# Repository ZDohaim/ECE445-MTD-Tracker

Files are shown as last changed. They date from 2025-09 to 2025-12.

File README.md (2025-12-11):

# ECE445-MTD-Tracker

## Champaign MTD Bus Tracker Map
Team Members:
Amber Wilt (anwilt2)
Daniel Vlassov (dvlas2)
Ziad Aldohaim (ziada2)
Problem
Champaign has a very large and complex bus system through the MTD. It can be hard for students to know when the buses are coming when they are in buildings such as the ECEB, since the bus times are only displayed at the stops. Furthermore, these buses can be late or early, causing students to miss their bus or not arrive at their destination on time.

### Solution
To fix this, we will come up with the design for a large display that shows real-time locations of all buses (color-coded using RGB) in the surrounding campus area. This can be used by students in buildings to easily visualize where the bus they want to take is currently located, making it easier for students to time when to leave classrooms and when to expect their ride. The display will update the locations approximately every 30 seconds and will light up every LED along a bus route every few minutes to make it easier for students to visualize which bus route they need to take. Furthermore, the system will include various light settings (theme/brightness).

### Solution Components
This system will mainly include the subsystems of the LED matrix, the controller, and the power supply.

#### Subsystem 1 - LED Matrix
The LED matrix will be located on a large PCB or 3D printed map of the city (cost dependent). This subsystem will be made of addressable LEDs, photoresistors to automatically modify the intensity of LEDs, and will be controlled by the microcontroller (to indicate positions).

#### Subsystem 2 - Microcontroller
The microcontroller will utilize wifi to access the MTD API to gather real-time bus data as well as provide control to individually address each LED within the matrix. Furthermore, it will control/communicate with other modules/displays in the system, such as a real-time clock or menu. The microcontroller will be an ESP32

#### Subsystem 3 - Power Supply
The power supply will provide ample power to a large number of LEDs (and the entire system). We will need to include a buck converter to step down the power supply to be usable by the LEDs.

## Criterion for Success
To demonstrate the success of our project, we will need to prove the accuracy of the data we are displaying (how accurate are bus timings/locations). Additionally, we will need to show that the data is easy to interpret for a user and can be utilized for easier bus system use.

## Demo Video
https://youtube.com/shorts/ADJun_s7ysQ?si=JwPbscHMFlE2qaHY

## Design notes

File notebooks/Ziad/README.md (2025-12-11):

# Ziad's Notebooks

## Week 1-2: September 29-October 5, 2025
### API Setup and Initial Testing

**Date: 09/24/2024**

**Objective:** Get MTD API and validate data structure

**Tasks Completed:**
- Registered and Received API key, from MTD and completed verification process.
- Set up Insomnia REST client for API testing
- Tested endpoints
 
Screenshot 2025-09-28 at 3 54 33 PM

- Retrieved JSON responses from all endpoints

**API Response Structure:**
```json
{
  "vehicles": [
    {
      "vehicle_id": "...",
      "trip": {
        "route_id": "ILLINI",
        "direction": "East"
      },
      "location": {
        "lat": 40.1092,
        "lon": -88.2272
      }
    }
  ]
}
```

## Week 3-4: October 6-12, 2025
### ESP32 Integration and Breadboard Demo

**Date: 10/05/2024**
**Some Issues faced: 

1. **TLS Certificate Validation:** Initially failed HTTPS connection
 Used `client.setInsecure()` to bypass certificate validation (acceptable for read-only public API)
2. **Using IllinoisNet**
  - Failed to connect to IllinoisNet due to Captive Portal to log in to student account, opted to using phone hotspot.

B54E72DD-15F0-4063-979C-1600B46E0ABB_1_105_c

**Flowchart**

Screenshot 2025-12-11 at 2 07 16 PM

## Week 5-6: October 13-27, 2025
### GPS Mapping Algorithm and LED Integration
**Date: 10/13/2024**
**Objective:** Test basic LED control and display live bus data for Illini Union Bus Stop Mock Demo 2

- Connected to MTD API and fetched live vehicle data
- Filtered JSON response for Illini Union route buses only
- Extracted latitude and longitude for each bus
- Applied simple linear scaling to approximate LED positions, based on (176 LEDs) small LED strip we have
- Updated LEDs every 60 seconds with new API data
**JSON Parsing Code:**
```cpp
for (JsonObject vehicle : doc["vehicles"].as()) {
    const char* route_id = vehicle["trip"]["route_id"];
    
    // Filter for Illini Union only
    if (strcmp(route_id, "ILLINI") == 0) {
        double lat = vehicle["location"]["lat"];
        double lon = vehicle["location"]["lon"];
        
        // Basic position estimation (simplified)
        int led_position = estimatePosition(lat, lon);
        strip.setPixelColor(led_position, strip.Color(255, 255, 255)); 
    }
}
strip.show();
```

https://github.com/user-attachments/assets/0354b601-5e5d-42b3-8681-6bb49f9fb9fd

## Week 7-9: October 27 - November 2, 2025
**Task:** Get Machine Shop Stand

### Machine Shop Coordination

- Get Board so Daniel can glue 3D printed segments of the map on it. 

Items from Machine Shop:

651D2E2C-DB3E-4684-9555-0176D12105F5_4_5005_c

## Week 10: November 3-9, 2025
**Task:** Finalize Code

### GPS Mapping Algorithm Development

**Objective:** Develop accurate GPS-to-LED coordinate transformation algorithm

**Problem Statement:**
Convert GPS coordinates (latitude/longitude) to discrete LED indices (0-873) representing exact physical positions on the map.

### Two-Step Algorithm

**Segment Identification**
- Defined 16 street segments with GPS bounding boxes
- Each segment has `minLat, maxLat, minLon, maxLat` boundaries

**Data Structure:**
```cpp
struct GPStoLED {
    const char* segment_name;
    std::vector ranges;
    double minLon, maxLon;
    double minLat, maxLat;
    bool reverse;
};
```
## Week 10: November 10-23, 2025
**Task** Finalize Code

### GPS Mapping, 

Segmented the Longitude and Latitude incorrectly, Amber and Daniel fixed.
Added functionality of the buttons, got stuck on the legend and holding button functionality, Daniel finalized it.
**Flowchart for button functionality**

Screenshot 2025-12-11 at 2 07 57 PM

Added photoresistor and brightness functionallity. 
Had to adjust some Routes, since the LEDs are connected serially and where a bit random based on the direction and the actual LED segment, so Amber helped a lot with diving that up and testing.

## Week 11: December 1-11, 2024
**Demo and Final Presentation Done** 

BUS DEMO

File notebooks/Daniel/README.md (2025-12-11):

# Daniel's Notebooks

This directory contains Daniel's notebooks and work for the ECE445 MTD Tracker project.

- 2025-09-03 - RFA Creation
- 2025-09-10 - Proposal Creation
- 2025-09-14
# 2025-09-3 - Brainstorming & RFA
First meeting to come up with potential ideas for senior design project.
- Initial Ideas:
  - 3D Printed Battle Bots - join the battle bot competition with professor gruev
  - Pill Sorter - automatically sort pills by days needed
  - Automatic Frozen Fish Feeder - keeps fish food frozen and automatically feeds the fish
  -nd  MTD Bus Visual - Live feed of the buses on campus ashows them on PCB/3D printer*

- MTD Bus Tracker Project Idea:
  - live tracking every 30 sec
  - two-way LED roads along 3d printed champaign
  - maybe include brightness, themes
  - 7-segment display for time or date?
  
# 2025-09-10 - Proposal Creation
Meeting to start creating proposal documentation
- Daniel: Visual aid and a block diagram.
- Brainstormed what the block diagram needs and what components we should consider using.

# 2025-09-14 - Block Diagram and Visual Aid
- Visual Aid
Visual Aid
  
- Block Diagram
blockDiagram

# 2025-09-20
- Basic design of the 3d model, making it simpler and figuring out the size

# 2025-10-6 
- Lab meeting, built out a simple breadboard with the LEDs, LED chase, button control, and photoresistor analog input.
- Added the Arduino code

# 2025-10-7
-Started the first 3d prints to get options for scale 
-3dmap

# 2025-10-14
-Design Doc Done
  
# 2025-10-14 - 11-20
-3d printing 25 tiles for the map

# 20205-10-20 - PCB Layout Rev1
- Routed all the traces on a PCB for the first iteration passes all PCB way tests
pcbrev1

# 2025-10-27 - TA Meeting: Breadboard Demo 2
-We showed tracking buses on a mock 3d map with a functioning PCB

# 2025-11-2 - PCB Soldering
-Soldered PCB
-tested all of the traces to make sure they work
-The linear regulator kept burning out
-Using bench power, able to flash simple test code to light up RGB LED

# 2025-11-10 - PCB Layout Rev 2
-Routed all the traces on the new iteration of the board, changed most of the layout to feature better placement of components, and new power system
pcbrev2

# 2025-11-11 - TA Meeting
-Still 3D printing the model 

# 2025-11-13 - Soldering PCB
- Soldered the new PCB rev 2 board and did the same test to make sure power and ESP32 flashing works, not tested on wall power
- PCBrev3

# 2025-11-18 - TA Meeting
-Demonstrated new PCB functioning on bench power supply and additional mapping of buses on LED strip

# 2025-11-29 - Physical Assembly Done
-Physically glued all 25 plates to the backboard and started designing a custom 3d printed border 
assebmled

# 2025-12-30 - Routing Led Strips
-Spent most of the day routing led strips through all roads buses go
-Worked on code for color matching to buses

# 2025-12-10 - Final Demo
-Final project with a custom menu for bus route selection
demo

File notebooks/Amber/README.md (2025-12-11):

# Amber's Notebooks
This directory contains Amber's notebooks and work for the ECE445 MTD Tracker project.

- 2025-09-03 - RFA Creation
- 2025-09-10 - Proposal Creation
- 2025-09-28 - Initial PCB Design
- 2025-10-2 - PCB Design and Components
- 2025-10-6 - More PCB Design and Components

# 2025-09-3 - Brainstorming & RFA
First meeting to come up with potential ideas for senior design project.
- Initial Ideas:
  - 3D Printed Battle Bots - join the battle bot competition with professor gruev
  - Pill Sorter - automatically sort pills by days needed
  - Automatic Frozen Fish Feeder - keeps fish food frozen and automatically feeds the fish
  - MTD Bus Visual - Live feed of the buses on campus and shows them on PCB/3D printer*

- MTD Bus Tracker Project Idea:
  - live tracking every 30 sec
  - two-way LED roads along 3d printed champaign
  - maybe include brightness, themes
  - 7-segment display?
  
# 2025-09-10 - Proposal Creation
Meeting to start creating proposal documentation
- Amber: make the introduction (problem and solution)
- Problem: students find bus routes too confusing, miss bus
- Solution: high-level design, why this is better than just a screen

# 2025-09-29 - PCB Design

- use the ESP32 s3 wroom 1 (wifi)

# 2025-10-2 - PCB Design and Components
- CL21A226MAQNNNE - 22uF
- CC0805KRX7R9BB104 - 100nF (2)
- CL21B105KBFNNNE - 1uF

- 

- Working File Uploaded

# 2025-10-6 - More PCB Components
-Capacitors:
  - [CL21A226MAQNNNE](https://www.digikey.com/en/products/detail/samsung-electro-mechanics/CL21A226MAYNNNE/10479857) - 22uF (decouple capacitor)
  - [CC0805KRX7R9BB104](https://www.digikey.com/en/products/detail/yageo/CC0805KRX7R9BB104/302874) - 0.1uF (4)   (decouple capacitor, enable capacitor, photoresistor capacitor)
  - [CL21B105KBFNNNE](https://www.digikey.com/en/products/detail/samsung-electro-mechanics/CL21B105KBFNNNE/3886687) - 1uF    (boot capacitor)
  - [TAJA106K016RNJ](https://www.digikey.com/en/products/detail/kyocera-avx/TAJA106K016RNJ/563762) - 10uF   (step down polarized capacitor)
  - [TCJB226M025R0150E](https://www.digikey.com/en/products/detail/kyocera-avx/TCJB226M025R0150E/10062672)](https://www.digikey.com/en/products/detail/kemet/T529P226M010AAE200/4246277) - 22uF   (step down   polarized capacitor)
  - barrel jack - https://www.digikey.com/en/products/detail/same-sky-formerly-cui-devices/PJ-080BH/3477153
  - USB - https://www.mouser.com/ProductDetail/GCT/USB4216-03-A?qs=Tc%252BHE9vUsnv1G2UWLFIexA%3D%3D
  - fuse - https://www.digikey.com/en/products/detail/bel-fuse-inc/0ZCF0500FF2A/10445775
  - Cap - https://www.digikey.com/en/products/detail/vishay-sfernice/T73YP103KT20/1587813
  - 3pin led connector - https://www.digikey.com/en/products/detail/te-connectivity-amp-connectors/282837-3/2187974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

# 2025-10-7: TA Meeting
- First PCB iteration due, reviewed design and submission
- Breadboard demo 1 - showed lighting up LED with breadboard

# 2025-10-14: TA Meeting
- Design document done

# 2025-10-16 - More PCB Design Work
- ESP32-S3 set up: (reference: https://documentation.espressif.com/esp32-s3-wroom-1_wroom-1u_datasheet_en.pdf)
  - 
  - 
  - https://www.youtube.com/watch?v=EdEwRXiQsfc  (microcontroller schematic design example)
  - https://www.youtube.com/watch?v=xK14eVJCoqU   (microcontroller schematic design example)
  - 

  - set up microcontroller based on datasheet and video references, as well as usb, boot/enable buttons, and input
 
# 2025-10-18 - Power Distribution Design
- Choose to use linear regulator for 5V to 3.3V step-down voltage from barrel jack input using
- Datasheet: http://www.advanced-monolithic.com/pdf/ds1117.pdf
- Preliminary Design:
  - 
- Logic level shifter for 3.3V to 5V step-up for LED data line:
  - Based off of schematic for SparkFun logic-level bidirectional
  - Data sheet: https://cdn.sparkfun.com/datasheets/BreakoutBoards/Logic_Level_Bidirectional.pdf
  - Example Schematic: 
  - Implemented Design: 

# 2025-10-20 - Photosensor Circuit
- Use analog output for ambient lights could use digital for 0 or 1 value
- 

# 2025-10-27 - TA Meeting: Breadboard Demo 2
- Showed actual tracking of buses along green street

# 2025-11-3 - PCB Testing
- soldered PCB and tested
- able to flash microcontroller via USB after trial/error and could light up debugging LEDs with code
- linear regulators don't work with wall supply
- have to redesign power distribution system and microcontroller set up

# 2025-11-10 - Second PCB Design
- New microcontroller set up for EN and Boot correct oritentation:
  -
- New power distribution circuit using a 5V to 3.3V converter to handle input noise or spikes in current/voltage draw
  - 

# 2025-11-11 - TA Meeting
- no new design changes, working on 3D printing (Daniel) and assembly

# 2025-11-18 - TA Meeting (Mock Demo)
- showed working PCB with programmable microcontroller and additional programming for mapping buses to the actual LED strips

# 2025-11-30 - Physical Assembly Done
-

# 2025-12-1 - Finishing Code
- created the coordinate mappings for each street mapped onto the display via google maps and used counter code to find the LED ranges for each strip
- example of mapping:  
- adjusted code for the mapping of LEDs now onto a one-way road

# 2025-12-10 - Final Demo :))))
- final design:
  -

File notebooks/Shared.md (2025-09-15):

# Shared Notebook:

# 03-09-2025 Brainstorming & Created RFA 
First time meeting as a team. We brainstormed different ideas:

Pill Sorter - automatically compartmentalize pills by days needed, just dump into dispenser and it does everything.
3D Printed Battle Bots - join the battle bot competition with professor Gruev
Automatic Frozen Fish Feeder - keeps fish food frozen and automatically feeds the fish
#MTD Bus Visual - Live feed of the buses on campus and shows them on PCB/3D printer

# 10-09-2025 Drafting with Proposal

Finalized the idea, and what was needed, split up the Proposal:
1. Introduction (Amber)
2. Design (Daniel)
3. Ethical Considerations (Ziad)

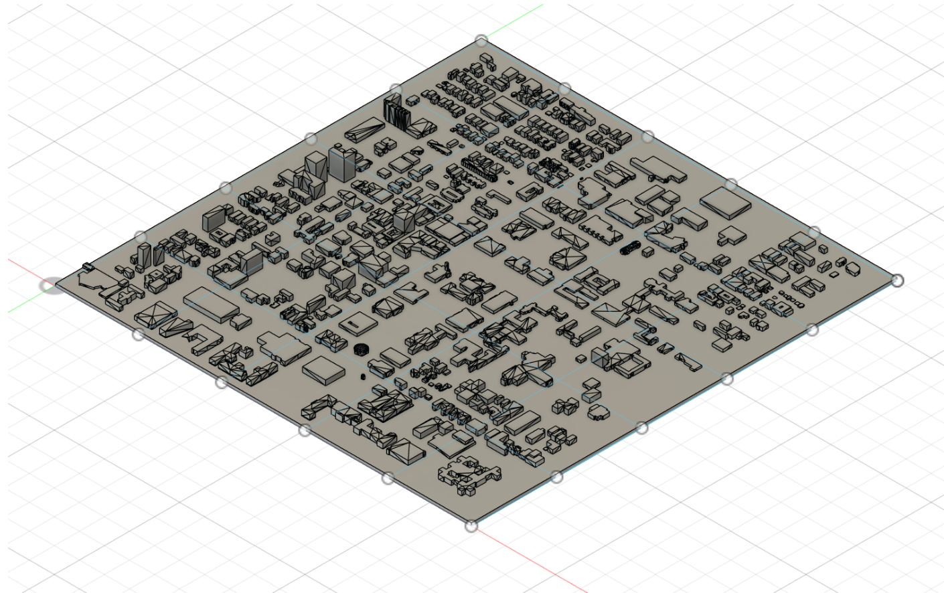
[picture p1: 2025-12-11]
notebooks/Daniel/3dmap.PNG

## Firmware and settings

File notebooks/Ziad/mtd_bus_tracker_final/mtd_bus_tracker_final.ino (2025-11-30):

#include <Wire.h>
#include <Adafruit_SSD1306.h>
#include <Adafruit_GFX.h>
#include <Adafruit_NeoPixel.h>
#include <ArduinoJson.h>
#include <WiFi.h>
#include <HTTPClient.h>
#include <WiFiClientSecure.h>

// WiFi credentials
const char* ssid = "iPhone";
const char* password = "11111111";

// MTD API endpoint
const char* apiURL = "https://developer.mtd.org/api/v2.2/json/GetVehicles?key=13d4773418a343cc902e31242d674e67";

// Pin definitions
#define PHOTORESISTOR_Analog 47
#define PHOTORESISTOR_out 39
#define BUTTON1_PIN 9
#define BUTTON2_PIN 10
#define BUTTON3_PIN 11
#define LED_PIN 3
#define LED_REDPIN 17
#define LED_GREENPIN 18
#define LED_BLUEPIN 8
#define NEOPIXEL_PIN 16
#define OLED_SDA_PIN 39
#define OLED_SCL_PIN 38
#define SSD1306_I2C_ADDRESS 0x3C

// LED strip setup
#define NUM_LEDS 1100
Adafruit_NeoPixel strip(NUM_LEDS, NEOPIXEL_PIN, NEO_GRB + NEO_KHZ800);

// OLED setup
#define SCREEN_WIDTH 128
#define SCREEN_HEIGHT 64
Adafruit_SSD1306 display(SCREEN_WIDTH, SCREEN_HEIGHT, &Wire, -1);

// Timing constants
#define API_UPDATE_INTERVAL 60000   // 60 seconds
#define ANIMATION_STEP_MS 25        // 25ms per LED (animation)


struct GPStoLED {
  const char* segment_name;
  float lat_min, lat_max; 
  float lon_min, lon_max;
  const char* orientation;  
  int led_out_start;        // going south [outbound (South/East/Urbana)]  [CHANGE THESE VALUES]
  int led_out_end;
  int led_in_start;         //going north [inbound (North/West/Champaign)] [CHANGE THESE VALUES]
  int led_in_end;
};



GPStoLED gps_mappings[] = {
  // WHITE STREET (East-West)
  {"White Third-Fourth", 40.114337, 40.114537, -88.235518, -88.233441, "EW", 0, 20, 20, 40},
  {"White Fourth-Fifth", 40.114337, 40.114537, -88.233641, -88.231997, "EW", 40, 60, 60, 80},
  {"White Fifth-Sixth", 40.114337, 40.114537, -88.232197, -88.230350, "EW", 80, 100, 100, 120},
  {"White Sixth-Wright", 40.114337, 40.114537, -88.230550, -88.228865, "EW", 120, 140, 140, 160},
  
  // WRIGHT STREET (North-South)
  {"Wright White-Stoughton", 40.113405, 40.114537, -88.229065, -88.228857, "NS", 160, 180, 180, 200},
  {"Wright Stoughton-Springfield", 40.112622, 40.113605, -88.229057, -88.228857, "NS", 200, 220, 220, 240},
  {"Wright Springfield-Healey", 40.111423, 40.112822, -88.229004, -88.228804, "NS", 240, 260, 260, 280},
  
  // GREEN STREET (East-West)
  {"Green Third-Fourth", 40.110150, 40.110369, -88.235498, -88.233441, "EW", 280, 300, 300, 320},
  {"Green Fourth-Fifth", 40.110169, 40.110389, -88.233641, -88.231958, "EW", 320, 340, 340, 360},
  {"Green Fifth-Sixth", 40.110189, 40.110389, -88.232158, -88.230288, "EW", 360, 380, 380, 400},
  {"Green Sixth-Wright", 40.110189, 40.110408, -88.230488, -88.228781, "EW", 400, 420, 420, 440},
  {"Green Wright-Mathews", 40.110208, 40.110579, -88.228981, -88.225500, "EW", 440, 460, 460, 480},
  {"Green Mathews-Goodwin", 40.110379, 40.110606, -88.225700, -88.223831, "EW", 480, 500, 500, 520},
  {"Green Goodwin-Lincoln", 40.110406, 40.110674, -88.224031, -88.219205, "EW", 520, 540, 540, 560},
  
  // UNIVERSITY AVENUE (East-West)
  {"University Gregory-Harvey", 40.116334, 40.116534, -88.220839, -88.222284, "EW", 560, 580, 580, 600},
  {"University Harvey-Goodwin", 40.116317, 40.116517, -88.222484, -88.223971, "EW", 600, 620, 620, 640},
  
  // GOODWIN AVENUE (North-South)
  {"Goodwin University-Clark", 40.115336, 40.116493, -88.224171, -88.223938, "NS", 640, 660, 660, 680},
  {"Goodwin Clark-Main", 40.114391, 40.115536, -88.224138, -88.223911, "NS", 680, 700, 700, 720},
  {"Goodwin Main-Springfield", 40.113425, 40.114591, -88.224111, -88.223911, "NS", 720, 740, 740, 760},
  
  // SPRINGFIELD AVENUE (East-West)
  {"Springfield Lincoln-Gregory", 40.112715, 40.112915, -88.219269, -88.220794, "EW", 760, 780, 780, 800},
  {"Springfield Gregory-Harvey", 40.112700, 40.112900, -88.220594, -88.222419, "EW", 800, 820, 820, 840},
  {"Springfield Harvey-Goodwin", 40.112687, 40.112887, -88.222219, -88.224084, "EW", 840, 860, 860, 880},
  
  // ILLINOIS STREET (East-West)
  {"Illinois Lincoln-Gregory", 40.108960, 40.109490, -88.219205, -88.221703, "EW", 880, 900, 900, 920},
  
  // GREGORY STREET (North-South)
  {"Gregory Illinois-Goodwin", 40.109190, 40.109490, -88.221503, -88.224000, "NS", 920, 940, 940, 960},
  
  // NEVADA STREET (East-West)
  {"Nevada Lincoln-Gregory", 40.105885, 40.106089, -88.219133, -88.221631, "EW", 960, 980, 980, 1000},
  {"Nevada Gregory-Goodwin", 40.105853, 40.106085, -88.221431, -88.223944, "EW", 1000, 1020, 1020, 1040}
};

const int NUM_GPS_MAPPINGS = sizeof(gps_mappings) / sizeof(gps_mappings[0]);


// MAJOR BUS STOPS - ALWAYS LIT UP 

struct BusStopLED {
  const char* stop_name;
  float lat, lon;
  int led_position;  // Major Stop LED POSITIONS [CHANGE THESE VALUES]
};

BusStopLED major_stops[] = {
  // Transit Plaza 
  {"Transit Plaza NW", 40.10847, -88.228957, 5},
  {"Transit Plaza NE", 40.108582, -88.228842, 6},
  {"Transit Plaza SW", 40.108202, -88.228923, 7},
  {"Transit Plaza SE", 40.108178, -88.228828, 8},
  
  // Illini Union 
  {"Illini Union South", 40.110364, -88.226834, 450},
  {"Illini Union North", 40.110447, -88.227402, 451},
  
  // ISR 
  {"ISR South", 40.10902, -88.22176, 550},
  {"ISR North", 40.10914, -88.22209, 551},
  
  // Krannert Center
  {"Krannert Center", 40.108291, -88.223785, 600},
  
  // White & Wright
  {"White & Wright", 40.114438, -88.228912, 140},
  
  // Stoughton & Wright
  {"Stoughton & Wright", 40.113602, -88.22901, 200},
  
  // Healey & Wright
  {"Healey & Wright E", 40.112038, -88.228853, 260},
  {"Healey & Wright NW", 40.111788, -88.228989, 261},
  
  // Green & Goodwin 
  {"Green & Goodwin SW", 40.11044, -88.224182, 500},
  {"Green & Goodwin NW", 40.110587, -88.224692, 501}
};
// might need to add more stops, these are the main ones (i think). 

const int NUM_MAJOR_STOPS = sizeof(major_stops) / sizeof(major_stops[0]);

// Variables
int intensity = 125;
unsigned long lastAPIUpdate = 0;

// Route cycling
const char* routes[] = {"TEAL", "GREEN", "GREENHOPPER", "ILLINI", "BLUE", "YELLOW", "YELLOWHOPPER", "RED"};
const int NUM_ROUTES = 8;
int currentRouteIndex = -1;
bool showingRouteColor = false;

// Bus tracking with animation support
struct Bus {
  char route_id[20];
  char direction[20];
  double lat;
  double lon;
  float current_led;      // Current position (to show moving from point to next point with animation)
  float target_led;       // Target position from API 
  bool active;
  bool animating;         
};

Bus buses[75];
int activeBusCount = 0;
bool busesAnimating = false;

void setup() {
  Serial.begin(115200);
  delay(2000);

  strip.begin();
  strip.setBrightness(125);
  strip.clear();
  strip.show();

  pinMode(LED_BUILTIN, OUTPUT);
  for (int i = 0; i < 5; i++) {
    digitalWrite(LED_BUILTIN, HIGH);
    delay(100);
    digitalWrite(LED_BUILTIN, LOW);
    delay(100);
  }

  Serial.println("\n=== MTD Bus Tracker Initializing ===");
  Serial.printf("GPS Mappings: %d\n", NUM_GPS_MAPPINGS);
  Serial.printf("Major Bus Stops: %d\n", NUM_MAJOR_STOPS);
  Serial.printf("Total LEDs: %d\n", NUM_LEDS);
  Serial.println("Features: GPS interpolation, smooth animation, bus stops always lit");

  Wire.begin(OLED_SDA_PIN, OLED_SCL_PIN);
  if (!display.begin(SSD1306_SWITCHCAPVCC, SSD1306_I2C_ADDRESS)) {
    Serial.println(F("SSD1306 failed"));
  } else {
    display.clearDisplay();
    display.setTextSize(1);
    display.setTextColor(SSD1306_WHITE);
    display.setCursor(0, 0);
    display.println("MTD Bus Tracker");
    display.println("Smooth Animation");
    display.printf("Stops: %d\n", NUM_MAJOR_STOPS);
    display.display();
  }

  pinMode(LED_PIN, OUTPUT);
  pinMode(BUTTON1_PIN, INPUT_PULLUP);
  pinMode(BUTTON2_PIN, INPUT_PULLUP);
  pinMode(PHOTORESISTOR_Analog, INPUT);

  for (int i = 0; i < 75; i++) {
    buses[i].active = false;
    buses[i].animating = false;
    buses[i].current_led = -1;
    buses[i].target_led = -1;
  }

  WiFi.begin(ssid, password);
  
  int attempts = 0;
  while (WiFi.status() != WL_CONNECTED && attempts < 50) {
    delay(500);
    Serial.print(".");
    attempts++;
  }

  if (WiFi.status() == WL_CONNECTED) {
    Serial.println("\nWiFi Connected!");
    Serial.print("IP: ");
    Serial.println(WiFi.localIP());

    fetchBusData();
    lastAPIUpdate = millis();
  } else {
    Serial.println("\nWiFi Failed!");
  }
}

void loop() {
  strip.setBrightness(125);

  // Check if it's time to fetch new data
  if (millis() - lastAPIUpdate > API_UPDATE_INTERVAL) {
    Serial.println("\n60 seconds passed, fetching data...");
    fetchBusData();
    lastAPIUpdate = millis();
  }

  // Animate buses if any are animating
  if (busesAnimating) {
    animateBuses();
  }

  // Button handling
  int button1State = digitalRead(BUTTON1_PIN);
  int button2State = digitalRead(BUTTON2_PIN);

  if (button1State == LOW) {
    currentRouteIndex++;
    if (currentRouteIndex >= NUM_ROUTES) {
      currentRouteIndex = -1;
      showingRouteColor = false;
      Serial.println("Button 1: Back to GPS");
    } else {
      showingRouteColor = true;
      Serial.printf("Button 1: Route %s\n", routes[currentRouteIndex]);
    }
    delay(300);
  }

  if (button2State == LOW) {
    Serial.println("Button 2: Manual refresh");
    fetchBusData();
    delay(300);
  }

  if (showingRouteColor) {
    uint32_t routeColor = getRouteColor(routes[currentRouteIndex]);
    for (int i = 0; i < NUM_LEDS; i++) {
      strip.setPixelColor(i, routeColor);
    }
    strip.show();
  } else {
    drawBuses();
  }

  updateDisplay();
  delay(10); 
}

// Find GPS mapping for a given lat/lon
int findGPSMapping(double lat, double lon) {
  for (int i = 0; i < NUM_GPS_MAPPINGS; i++) {
    if (lat >= gps_mappings[i].lat_min && lat <= gps_mappings[i].lat_max &&
        lon >= gps_mappings[i].lon_min && lon <= gps_mappings[i].lon_max) {
      return i;
    }
  }
  return -1;
}

// Determine if direction is outbound (South/East/Urbana) or inbound (North/West/Champaign)
bool isOutboundDirection(const char* direction) {
  if (!direction) return true;
  
  String dir = String(direction);
  dir.toLowerCase();
  
  if (dir.indexOf("south") >= 0 || dir.indexOf("east") >= 0 || dir.indexOf("urbana") >= 0) {
    return true;
  }
  else if (dir.indexOf("north") >= 0 || dir.indexOf("west") >= 0 || dir.indexOf("champaign") >= 0) {
    return false;
  }
  
  return true;
}

// Calculate LED position with GPS interpolation (Option B - smooth)
float calculateLEDPosition(double lat, double lon, int mapping_idx, const char* direction) {
  if (mapping_idx < 0 || mapping_idx >= NUM_GPS_MAPPINGS) {
    return -1;
  }
  
  GPStoLED mapping = gps_mappings[mapping_idx];
  bool isOutbound = isOutboundDirection(direction);
  
  int led_start = isOutbound ? mapping.led_out_start : mapping.led_in_start;
  int led_end = isOutbound ? mapping.led_out_end : mapping.led_in_end;
  
  float position = led_start;
  
  if (strcmp(mapping.orientation, "EW") == 0) {
    // East-West: use longitude
    float lon_range = mapping.lon_max - mapping.lon_min;
    if (abs(lon_range) < 0.000001) {
      position = led_start;
    } else {
      float norm = (lon - mapping.lon_min) / lon_range;
      
      // For westbound (inbound), reverse direction
      if (!isOutbound) {
        norm = 1.0 - norm;
      }
      
      if (norm < 0) norm = 0;
      if (norm > 1) norm = 1;
      position = led_start + (norm * (led_end - led_start));
    }
  } 
  else if (strcmp(mapping.orientation, "NS") == 0) {
    // North-South: use latitude
    float lat_range = mapping.lat_max - mapping.lat_min;
    if (abs(lat_range) < 0.000001) {
      position = led_start;
    } else {
      float norm = (mapping.lat_max - lat) / lat_range;
      
      // For northbound (inbound), reverse direction
      if (!isOutbound) {
        norm = 1.0 - norm;
      }
      
      if (norm < 0) norm = 0;
      if (norm > 1) norm = 1;
      position = led_start + (norm * (led_end - led_start));
    }
  }
  
  if (position < led_start) position = led_start;
  if (position >= led_end) position = led_end - 1;
  
  return position;
}

void fetchBusData() {
  Serial.println("\n=== Fetching Bus Data ===");
  Serial.printf("Free heap: %d bytes\n", ESP.getFreeHeap());

  if (WiFi.status() != WL_CONNECTED) {
    Serial.println("WiFi not connected!");
    return;
  }

  WiFiClientSecure client;
  client.setInsecure();
  HTTPClient http;
  http.begin(client, apiURL);
  int httpCode = http.GET();

  Serial.printf("HTTP Response Code: %d\n", httpCode);
  
  if (httpCode == 200) {
    String payload = http.getString();
    Serial.printf("API Response received, length: %d bytes\n", payload.length());

    DynamicJsonDocument doc(65536);
    DeserializationError error = deserializeJson(doc, payload);
    
    if (error) {
      Serial.print("JSON parse failed: ");
      Serial.println(error.c_str());
      http.end();
      return;
    }

    Serial.println("JSON parsed successfully!");

    // Mark all buses as inactive first
    for (int i = 0; i < 75; i++) {
      buses[i].active = false;
    }

    int busIndex = 0;
    int onRouteCount = 0;
    int totalBusesScanned = 0;
    int outboundCount = 0;
    int inboundCount = 0;

    for (JsonObject vehicle : doc["vehicles"].as<JsonArray>()) {
      totalBusesScanned++;
      
      if (busIndex >= 75) break;

      const char* route_id = vehicle["trip"]["route_id"];
      if (!route_id || strlen(route_id) == 0) continue;

      double lat = vehicle["location"]["lat"];
      double lon = vehicle["location"]["lon"];
      const char* direction = vehicle["trip"]["direction"];

      int mapping_idx = findGPSMapping(lat, lon);
      
      if (mapping_idx >= 0) {
        float new_led_position = calculateLEDPosition(lat, lon, mapping_idx, direction);
        
        if (new_led_position >= 0) {
          strcpy(buses[busIndex].route_id, route_id);
          
          if (direction) {
            strncpy(buses[busIndex].direction, direction, 19);
            buses[busIndex].direction[19] = '\0';
          } else {
            strcpy(buses[busIndex].direction, "Unknown");
          }
          
          buses[busIndex].lat = lat;
          buses[busIndex].lon = lon;
          buses[busIndex].active = true;
          
          // Set up animation from current to target position
          if (buses[busIndex].current_led < 0) {
            // New bus, no animation needed
            buses[busIndex].current_led = new_led_position;
            buses[busIndex].target_led = new_led_position;
            buses[busIndex].animating = false;
          } else {
            // Existing bus, animate to new position
            buses[busIndex].target_led = new_led_position;
            buses[busIndex].animating = true;
            busesAnimating = true;
          }

          bool isOutbound = isOutboundDirection(direction);
          if (isOutbound) outboundCount++;
          else inboundCount++;

          Serial.printf("Bus %d: %s (%s) [%s] on %s at LED %.1f\n", 
                        busIndex, route_id, buses[busIndex].direction,
                        isOutbound ? "OUT" : "IN",
                        gps_mappings[mapping_idx].segment_name,
                        new_led_position);
          
          onRouteCount++;
          busIndex++;
        }
      }
    }

    activeBusCount = onRouteCount;
    Serial.printf("\n=== Summary ===\n");
    Serial.printf("Total buses: %d\n", totalBusesScanned);
    Serial.printf("On tracked routes: %d\n", onRouteCount);
    Serial.printf("  Outbound: %d\n", outboundCount);
    Serial.printf("  Inbound: %d\n", inboundCount);
  }
  
  http.end();
}

// Animate all buses simultaneously (moving window with fade)
void animateBuses() {
  static unsigned long lastAnimationStep = 0;
  
  if (millis() - lastAnimationStep < ANIMATION_STEP_MS) {
    return;  // sitll not the time for next animation 
  }
  
  lastAnimationStep = millis();
  bool anyBusAnimating = false;
  
  // Move all animating buses one step
  for (int i = 0; i < 75; i++) {
    if (buses[i].active && buses[i].animating) {
      float diff = buses[i].target_led - buses[i].current_led;
      
      if (abs(diff) < 0.5) {
        // Close enough, snap to target
        buses[i].current_led = buses[i].target_led;
        buses[i].animating = false;
      } else {
        // Move one step toward target
        if (diff > 0) {
          buses[i].current_led += 1.0;
        } else {
          buses[i].current_led -= 1.0;
        }
        anyBusAnimating = true;
      }
    }
  }
  
  busesAnimating = anyBusAnimating;
}

void drawBuses() {
  strip.clear();

  // Draw major bus stops (always on, dim white)
  for (int i = 0; i < NUM_MAJOR_STOPS; i++) {
    int led = major_stops[i].led_position;
    if (led >= 0 && led < NUM_LEDS) {
      strip.setPixelColor(led, strip.Color(20, 20, 20));  // Dim white
    }
  }

  // Draw active buses with trail effect
  for (int i = 0; i < 75; i++) {
    if (buses[i].active) {
      int ledPos = (int)buses[i].current_led;
      
      if (ledPos >= 0 && ledPos < NUM_LEDS) {
        uint32_t color = getRouteColor(buses[i].route_id);
        
        // Main bus LED (bright)
        strip.setPixelColor(ledPos, color);
        
        // Trailing LED (dim)
        if (ledPos > 0) {
          strip.setPixelColor(ledPos - 1, strip.Color(
            (color >> 16 & 0xFF) / 4,
            (color >> 8 & 0xFF) / 4,
            (color & 0xFF) / 4
          ));
        }
      }
    }
  }

  strip.show();
}

uint32_t getRouteColor(const char* route_id) {
  if (strcmp(route_id, "TEAL") == 0) return strip.Color(0, 128, 128);
  if (strcmp(route_id, "GREEN") == 0 || strcmp(route_id, "GREENHOPPER") == 0 || strcmp(route_id, "GREEN EXPRESS") == 0) return strip.Color(0, 255, 0);
  if (strcmp(route_id, "ILLINI") == 0) return strip.Color(90, 29, 90);
  if (strcmp(route_id, "YELLOW") == 0 || strcmp(route_id, "YELLOWHOPPER") == 0) return strip.Color(255, 255, 0);
  if (strcmp(route_id, "RED") == 0) return strip.Color(255, 0, 0);
  if (strcmp(route_id, "BLUE") == 0) return strip.Color(0, 0, 255);
  if (strcmp(route_id, "BROWN") == 0) return strip.Color(139, 69, 19);
  if (strcmp(route_id, "ORANGE") == 0) return strip.Color(255, 165, 0);
  if (strcmp(route_id, "PINK") == 0) return strip.Color(255, 105, 180);
  if (strcmp(route_id, "GOLD") == 0 || strcmp(route_id, "GOLDHOPPER") == 0) return strip.Color(255, 215, 0);
  if (strcmp(route_id, "GREY") == 0 || strcmp(route_id, "GRAY") == 0) return strip.Color(128, 128, 128);
  if (strcmp(route_id, "SILVER") == 0) return strip.Color(192, 192, 192);
  if (strcmp(route_id, "BRONZE") == 0) return strip.Color(205, 127, 50);
  if (strcmp(route_id, "LAVENDER") == 0) return strip.Color(230, 230, 250);
  if (strcmp(route_id, "NAVY") == 0) return strip.Color(0, 0, 128);
  if (strcmp(route_id, "RAVEN") == 0) return strip.Color(50, 50, 50);
  if (strcmp(route_id, "LINK") == 0) return strip.Color(100, 149, 237);
  return strip.Color(255, 255, 255);
}

void updateDisplay() {
  display.clearDisplay();
  display.setCursor(0, 0);
  display.setTextSize(1);

  if (showingRouteColor) {
    display.println("Route Display");
    display.println("---------------");
    display.printf("Route: %s\n", routes[currentRouteIndex]);
    display.println("\nBtn1: Next route");
  } else {
    display.println("MTD Bus Tracker");
    display.println("Live Tracking");
    display.println("---------------");
    display.printf("Active: %d\n", activeBusCount);
    display.printf("Animating: %s\n", busesAnimating ? "YES" : "NO");
    display.println("\nBtn1: Routes");
    display.println("Btn2: Refresh");
  }

  display.display();
}

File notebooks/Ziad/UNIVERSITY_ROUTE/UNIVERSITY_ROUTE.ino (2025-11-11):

#include <Wire.h>
#include <Adafruit_SSD1306.h>
#include <Adafruit_GFX.h>
#include <Adafruit_NeoPixel.h>
#include <ArduinoJson.h>
#include <WiFi.h>
#include <HTTPClient.h>
#include <WiFiClientSecure.h>

// WiFi credentials
const char* ssid = "iPhone";
const char* password = "11111111";

// MTD API endpoint
const char* apiURL = "https://developer.mtd.org/api/v2.2/json/GetVehicles?key=13d4773418a343cc902e31242d674e67";

// Pin definitions
#define PHOTORESISTOR_PIN 1
#define BUTTON1_PIN 4
#define BUTTON2_PIN 5
#define LED_PIN 36
#define LED_BUILTIN 48
#define NEOPIXEL_PIN 16
#define OLED_SDA_PIN 39
#define OLED_SCL_PIN 38
#define SSD1306_I2C_ADDRESS 0x3C

// LED strip setup
#define NUM_LEDS 156
Adafruit_NeoPixel strip(NUM_LEDS, NEOPIXEL_PIN, NEO_GRB + NEO_KHZ800);

// OLED setup
#define SCREEN_WIDTH 128
#define SCREEN_HEIGHT 64
Adafruit_SSD1306 display(SCREEN_WIDTH, SCREEN_HEIGHT, &Wire, -1);

// Timing constants
#define API_UPDATE_INTERVAL 60000   
#define BUS_MOVEMENT_INTERVAL 30000  

// Geographic bounds for the tracked route segment
// White Street coordinates
#define WHITE_STREET_START_LON -88.237091  // White & 2nd
#define WHITE_STREET_END_LON -88.230445    // White & Wright (turn)
#define WHITE_STREET_LAT 40.114400         // Approximate latitude for White Street

// Wright Street coordinates
#define WRIGHT_TURN_LAT 40.114424          // White & Wright (turn)
#define WRIGHT_END_LAT 40.111529           // Healey & Wright

// LED segment definitions
#define LED_WHITE_START 0
#define LED_WHITE_END 58
#define LED_WRIGHT_START 58
#define LED_WRIGHT_END 78
#define LED_RETURN_OFFSET 78  // Return traffic starts at LED 78

// Variables
int intensity = 125;
unsigned long lastAPIUpdate = 0;
unsigned long lastBusMovement = 0;

// Route cycling for Button 1
const char* routes[] = {"TEAL", "GREEN", "GREENHOPPER", "ILLINI", "BLUE", "YELLOW", "YELLOWHOPPER", "RED"};
const int NUM_ROUTES = 8;
int currentRouteIndex = -1;
bool showingRouteColor = false;

// Bus tracking structure
struct Bus {
  char route_id[20];
  char direction[20];
  double lat;
  double lon;
  float led_position;
  bool active;
};

Bus buses[75];
int activeBusCount = 0;

void setup() {
  Serial.begin(115200);
  delay(2000);

  strip.begin();
  strip.setBrightness(125);
  strip.clear();
  strip.show();

  pinMode(LED_BUILTIN, OUTPUT);
  for (int i = 0; i < 5; i++) {
    digitalWrite(LED_BUILTIN, HIGH);
    delay(100);
    digitalWrite(LED_BUILTIN, LOW);
    delay(100);
  }

  Serial.println("\n=== MTD Bus Tracker Initializing ===");
  Serial.println("Route Segment: White St (2nd to Wright) + Wright St (White to Healey)");
  Serial.printf("LED Layout:\n");
  Serial.printf("  0-58: White St Eastbound\n");
  Serial.printf("  58-78: Wright St Southbound\n");
  Serial.printf("  78-136: White St Westbound (return)\n");
  Serial.printf("  136-156: Wright St Northbound (return)\n");

  Wire.begin(OLED_SDA_PIN, OLED_SCL_PIN);
  if (!display.begin(SSD1306_SWITCHCAPVCC, SSD1306_I2C_ADDRESS)) {
    Serial.println(F("SSD1306 allocation failed - continuing without display"));
  } else {
    display.clearDisplay();
    display.setTextSize(1);
    display.setTextColor(SSD1306_WHITE);
    display.setCursor(0, 0);
    display.println("MTD Bus Tracker");
    display.println("White/Wright Route");
    display.display();
  }

  pinMode(LED_PIN, OUTPUT);
  pinMode(BUTTON1_PIN, INPUT_PULLUP);
  pinMode(BUTTON2_PIN, INPUT_PULLUP);
  pinMode(PHOTORESISTOR_PIN, INPUT);

  for (int i = 0; i < 75; i++) {
    buses[i].active = false;
  }

  Serial.print("Connecting to WiFi: ");
  Serial.println(ssid);
  WiFi.begin(ssid, password);

  display.clearDisplay();
  display.setCursor(0, 0);
  display.print("Connecting WiFi...");
  display.display();

  int attempts = 0;
  while (WiFi.status() != WL_CONNECTED && attempts < 50) {
    delay(500);
    Serial.print(".");
    attempts++;
  }

  if (WiFi.status() == WL_CONNECTED) {
    Serial.println("\nWiFi Connected!");
    Serial.print("IP: ");
    Serial.println(WiFi.localIP());

    display.clearDisplay();
    display.setCursor(0, 0);
    display.print("WiFi Connected!");
    display.setCursor(0, 10);
    display.print(WiFi.localIP());
    display.display();
    delay(2000);

    fetchBusData();
    lastAPIUpdate = millis();
    lastBusMovement = millis();
  } else {
    Serial.println("\nWiFi Failed!");
    display.clearDisplay();
    display.setCursor(0, 0);
    display.print("WiFi Failed!");
    display.display();
  }
}

void loop() {
  strip.setBrightness(125);

  // API polling every 60 seconds
  if (millis() - lastAPIUpdate > API_UPDATE_INTERVAL) {
    Serial.println("\n60 seconds passed, fetching data...");
    fetchBusData();
    lastAPIUpdate = millis();
  }

  // Interpolate bus movement every 30 seconds
  if (millis() - lastBusMovement > BUS_MOVEMENT_INTERVAL) {
    moveBuses();
    lastBusMovement = millis();
  }

  // Button handling
  int button1State = digitalRead(BUTTON1_PIN);
  int button2State = digitalRead(BUTTON2_PIN);

  if (button1State == LOW) {
    currentRouteIndex++;
    if (currentRouteIndex >= NUM_ROUTES) {
      currentRouteIndex = -1;
      showingRouteColor = false;
      Serial.println("Button 1: Back to GPS tracking mode");
    } else {
      showingRouteColor = true;
      Serial.printf("Button 1: Showing route %s\n", routes[currentRouteIndex]);
    }
    delay(300);
  }

  if (button2State == LOW) {
    Serial.println("Button 2: Manual data refresh");
    fetchBusData();
    delay(300);
  }

  // Display mode
  if (showingRouteColor) {
    // Show entire strip in one color
    uint32_t routeColor = getRouteColor(routes[currentRouteIndex]);
    for (int i = 0; i < NUM_LEDS; i++) {
      strip.setPixelColor(i, routeColor);
    }
    strip.show();
  } else {
    // Show live GPS-mapped buses
    drawBuses();
  }

  updateDisplay();
  delay(1000);
}

bool isOnTrackedRoute(double lat, double lon) {
  // Check if bus is on White Street segment
  bool onWhiteStreet = (lat >= 40.1143 && lat <= 40.1148) && 
                       (lon >= -88.238 && lon <= -88.228);
  
  // Check if bus is on Wright Street segment
  bool onWrightStreet = (lat >= 40.1115 && lat <= 40.1148) &&
                        (lon >= -88.2295 && lon <= -88.2285);
  
  return onWhiteStreet || onWrightStreet;
}
}

bool isOutboundDirection(const char* direction) {
  String dir = String(direction);
  dir.toLowerCase();
  
  // Outbound: going away from campus (East on White, South on Wright, toward Urbana)
  if (dir.indexOf("south") >= 0 || dir.indexOf("east") >= 0 || dir.indexOf("urbana") >= 0) {
    return true;
  }
  // Return: going toward campus (West on White, North on Wright, toward Champaign)
  else if (dir.indexOf("north") >= 0 || dir.indexOf("west") >= 0 || dir.indexOf("champaign") >= 0) {
    return false;
  }
  
  // Default to outbound if unknown
  return true;
}
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

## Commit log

2025-10-03 pcb components
2025-10-03 initial PCB design (not all footprints & no trace)
    [mtd_pcb.kicad_pcb, mtd_pcb.kicad_sch]
2025-10-07 list of parts for PCB.md
2025-10-07 pcb parts.md
2025-10-07 API Connected to ESP32 (for BreadBoard Demo1)
2025-10-07 Add entry for ESP32 Breadboard Demo
2025-10-08 Add files via upload
    Made gerber files
2025-11-30 Add files via upload
    needs adjusting LED positions, and testing
    check: [CHANGE THESE VALUES]
2025-12-02 Add files via upload
    led strip
2025-12-11 update REEADME
    Added flowchart images and updated project details for weeks 5-11.
